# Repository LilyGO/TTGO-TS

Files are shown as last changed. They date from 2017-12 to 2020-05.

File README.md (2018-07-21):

## TTGO-TS

### TS V1.4

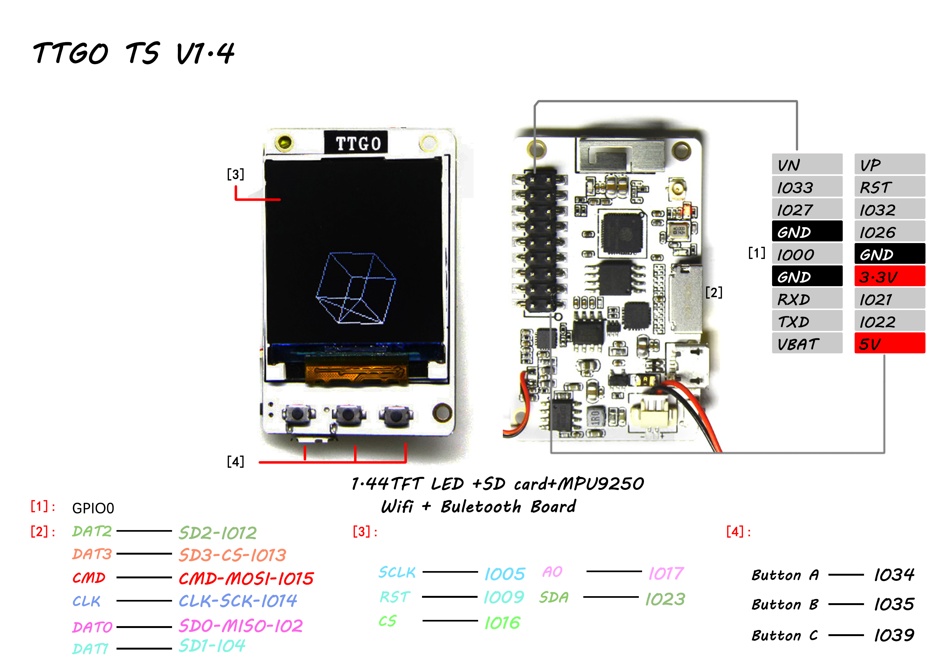
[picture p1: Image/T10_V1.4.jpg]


### TS V1.2

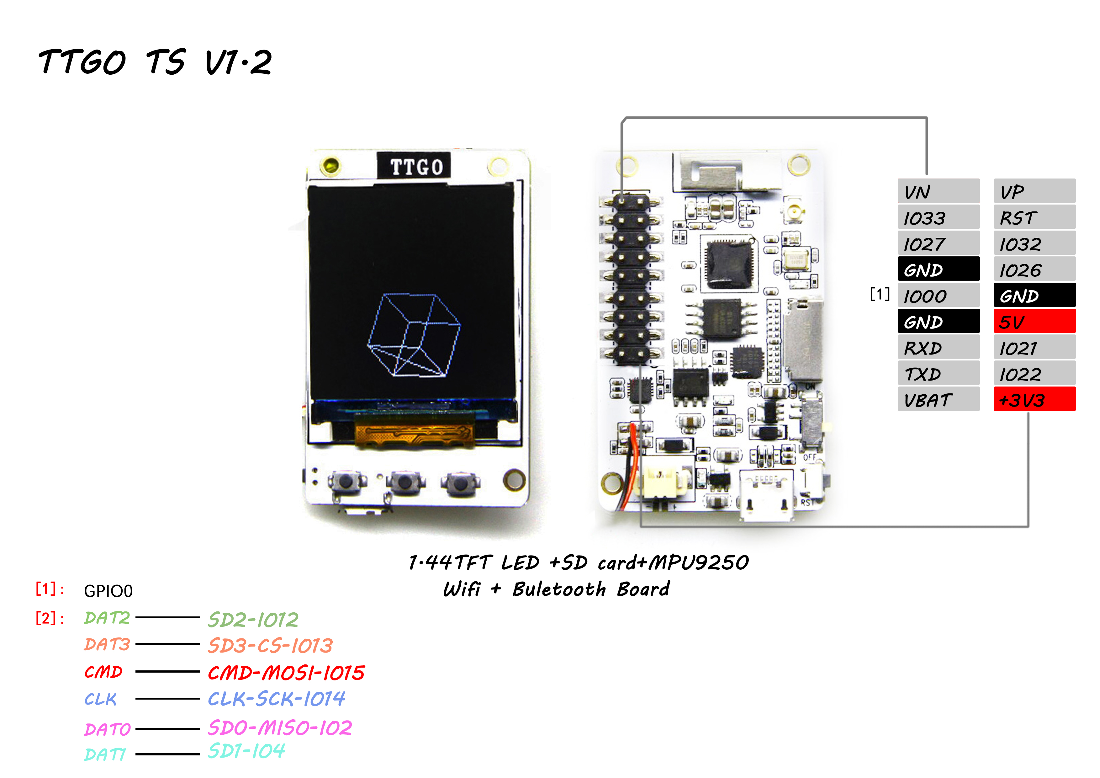
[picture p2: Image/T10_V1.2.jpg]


## TTGO-TS-V1.0

CS  16

DC  17

SDA 23

SCK 5

RST 9

## 3D shell

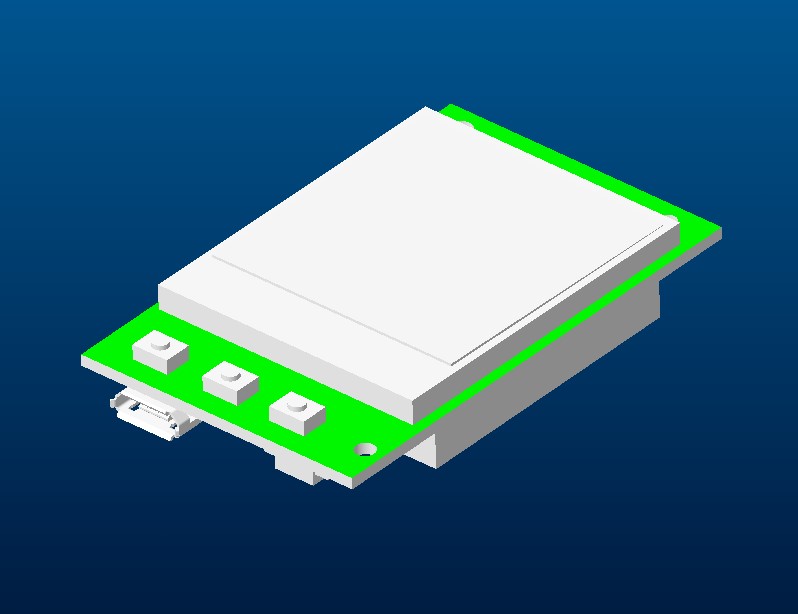
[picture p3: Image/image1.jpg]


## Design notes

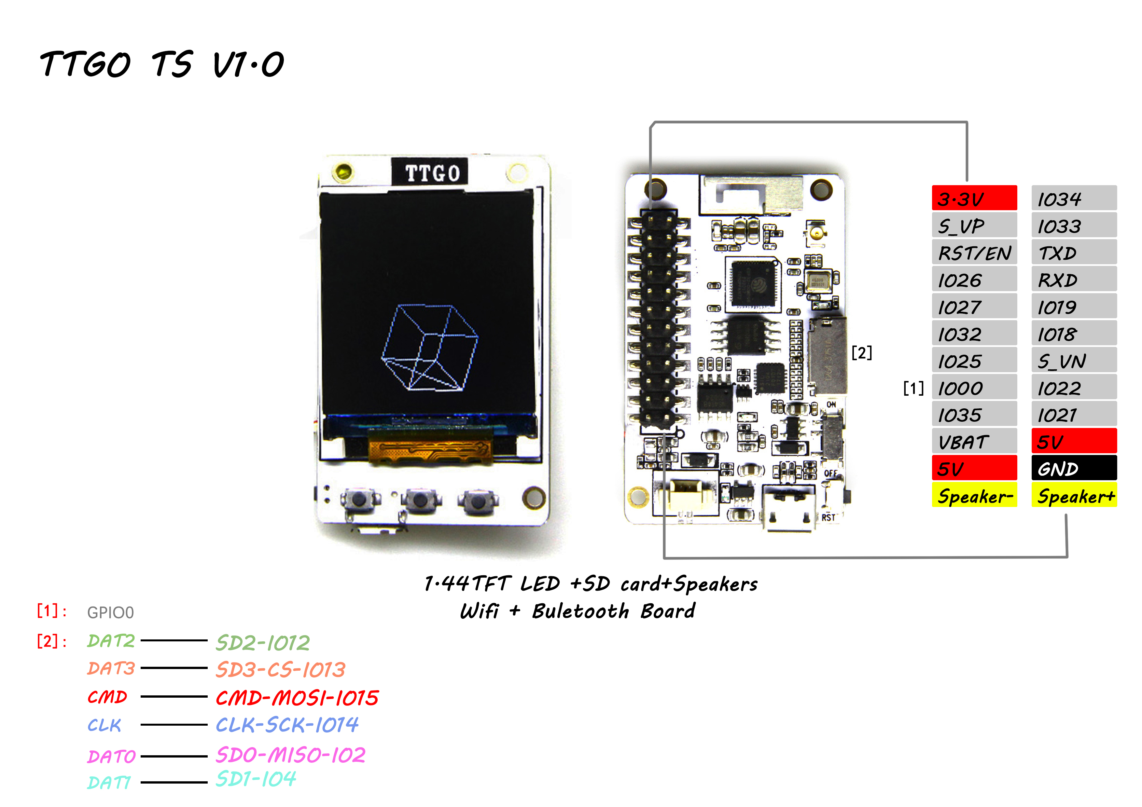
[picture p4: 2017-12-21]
Image/TS V1.0.jpg

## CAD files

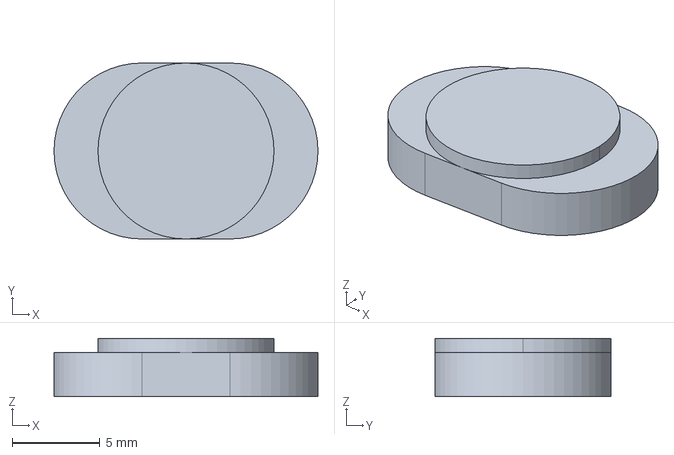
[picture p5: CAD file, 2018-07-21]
stp_file/laba.stp
15.0 x 10.0 x 3.30 mm

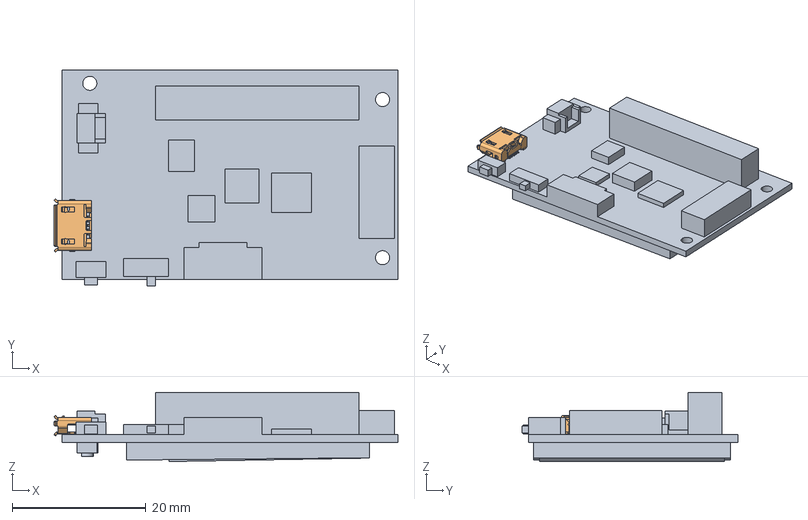
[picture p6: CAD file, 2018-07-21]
stp_file/pcb.stp
51.4 x 32.3 x 10.3 mm

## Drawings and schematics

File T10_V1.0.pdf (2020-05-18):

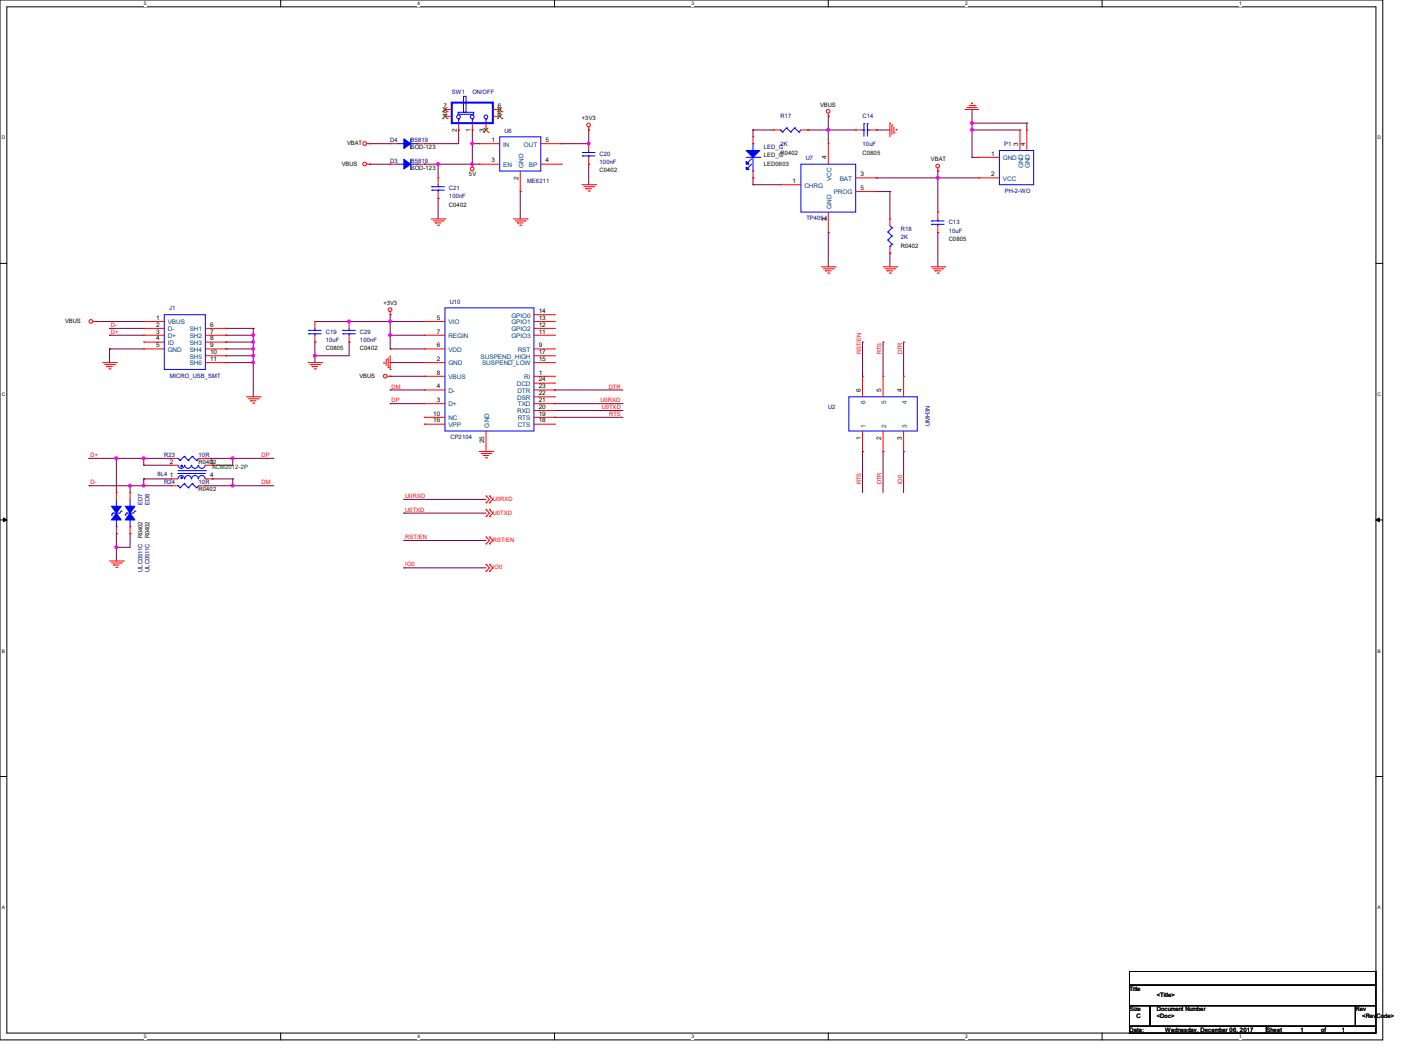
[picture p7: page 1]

2KR0402 U10 CP2104 VIO 5 REGIN 7 VDD 6 GND 2 VBUS 8 D- 4 D+

C C

# LED_4*15mA SCL/IO5 SDA/IO23 DC/IO17 CS/IO16 RST/EN

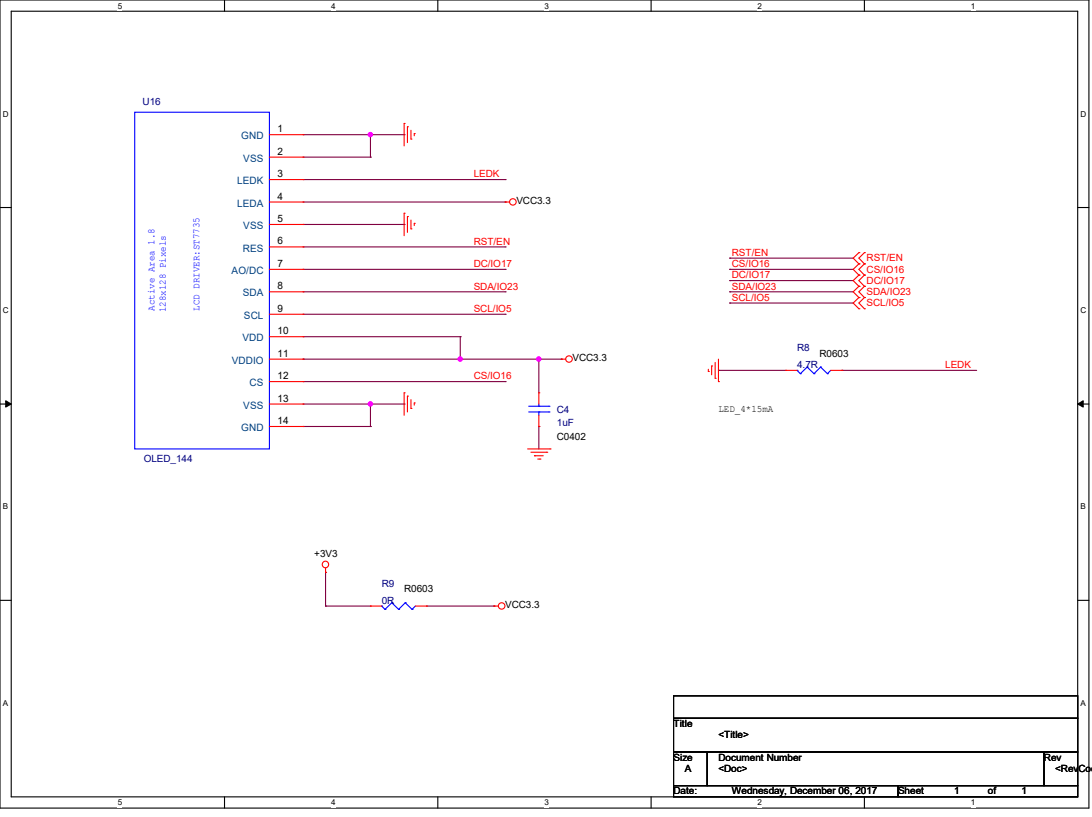
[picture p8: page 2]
LEDK; DC/IO17 SDA/IO23 SCL/IO5 CS/IO16 VCC3.3; VCC3.3 +3V3; VCC3.3; Title Size; Document Number; Rev Date:; Sheet; of <Doc>; <RevCode>; <Title> A; Wednesday, December 06, 2017; 1 Title Size; 1uF C0402 Active Area 1.8 128x128 Pixels; LCD DRIVER:ST7735 U16; OLED_144; GND; 1 VSS; LEDA; 4 VSS; 5 RES; 7 SDA; 8 SCL; 9 VDD; 10 VDDIO; 12 VSS; 13 GND

LEDK RST/EN

RST/EN
CS/IO16 DC/IO17 SDA/IO23 SCL/IO5

C C

+3V3

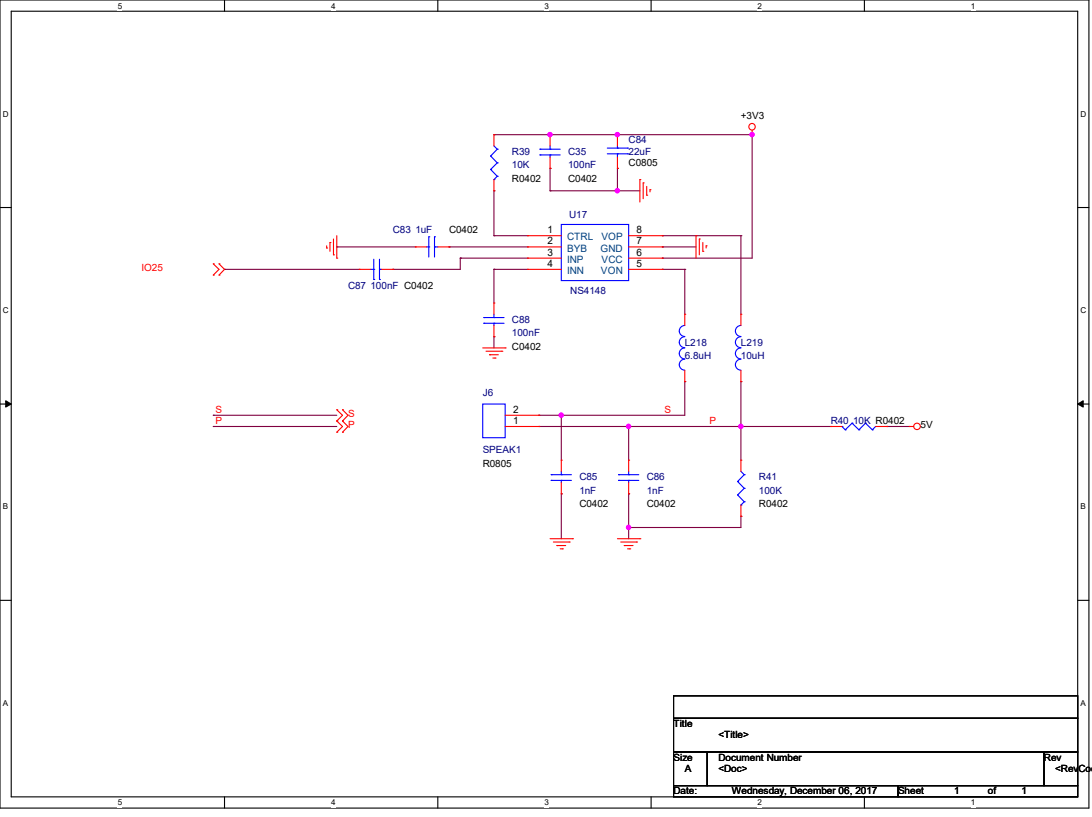
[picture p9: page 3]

# IO0 SD1-IO4 SD0-MISO-IO2SD2-IO12 CLK-SCK-IO14

# IO0 U0RXD

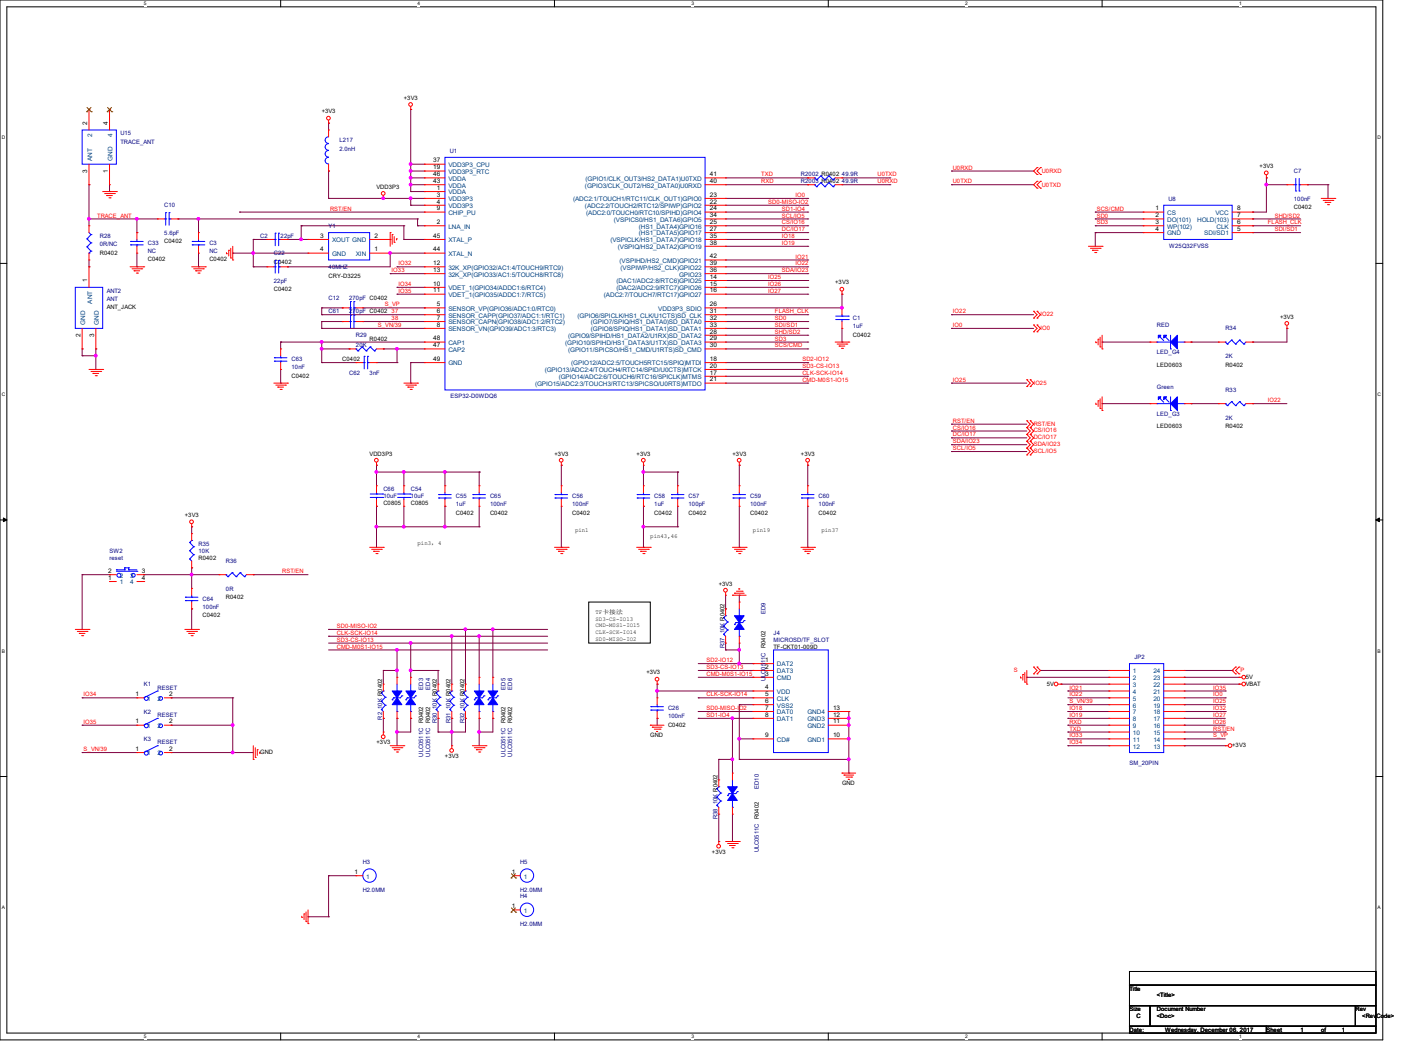
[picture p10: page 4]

SHD/SD2 TXD
IO18 DC/IO17 CS/IO16 SCL/IO5 RXD

SCL/IO5 SDA/IO23 DC/IO17 CS/IO16 RST/EN

CS/IO16 DC/IO17 SDA/IO23 SCL/IO5 RST/EN

1 R³⁷ ¹⁰K R⁰⁴⁰² ED⁶ ULC⁰⁵¹¹C R⁰⁴⁰² C54

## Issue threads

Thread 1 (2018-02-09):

MPU9250

donesnowangel, 2018-02-09:
Hi, I'm trying to work with the MPU9250 onboard the board with 1.8 inch screen. Can you please give me some guidance as to how to use it? What pins it is on? Is it on I2C or SPI? I've tried using various sketches examples and libraries, but without any success. An i2c scanner says there are no devices and when I try to get an a WHO_AM_I, I get a 0xFF.

Thanks,
Daniel

circuitsforfun, 2018-02-18:
Same problem here, I have both the 1.4" and 1.8" screen version and can't get the MPU9250 to work.
It would be great to see some example code provided or the schematic so I can see how it is connected.

donesnowangel, 2018-02-18:
I actually got it to work. Apparently the IMU uses pins 19 and 18 for SDA and SCL. So if you use the standard Wire.h library, add Wire.begin(19,18);

Daniel

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

circuitsforfun, 2018-02-18:
Ahh yes, that did the trick... thank you!

BeatArnet, 2018-05-19:
Hi, Could you please post an arduino example with the MPU9250. Thanks a lot.

LilyGO, 2018-12-19:
https://github.com/LilyGO/TTGO-TS-V1.2/blob/master/MPU9/MPU9.ino

kotakomputer, 2019-06-20:
TTGO V2.1_1.6 does not have PIN 18. Any recomended PIN?

Closed 2018-12-19.

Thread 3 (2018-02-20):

button example - strange behavior

GittaHuby, 2018-02-20:
The button example does not work properly: If i press btn A down it works as expected. While releasing btn A the serial monitor writes 'btn B released'. Physically buttons B and C without any function. Any idea?

kosso, 2018-03-12:
Through some trial and error I have discovered the v1.2 board (with gyro) has these pin numbers for the three pins (using the same orientation as the photo) :
~~~
LEFT 35
MIDDLE 34
RIGHT 39
~~~

Note: Some of the examples use M5Stack.h (from a very similar board. Is this a dev version?) which defines BUTTON_A_PIN 39, BUTTON_B_PIN 38 and BUTTON_C_PIN 37 which are wrong (at least for the V1.2 board containing the gyro and fewer physical pins).

This is why the example doesn't work.

jvhaarst, 2018-06-02:
This works for me :
```
#include <RBD_Timer.h>  // https://github.com/alextaujenis/RBD_Timer
#include <RBD_Button.h> // https://github.com/alextaujenis/RBD_Button

// input pullup enabled by default
RBD::Button left_button(35);
RBD::Button middle_button(34);
RBD::Button right_button(39);

void setup() {
  Serial.begin(115200);
}

void loop() {
  if(left_button.onPressed()) {
    Serial.println("Left Button Pressed");
  }

  if(left_button.onReleased()) {
    Serial.println("Left Button Released");
  }
  if(middle_button.onPressed()) {
    Serial.println("Middle Button Pressed");
  }

  if(middle_button.onReleased()) {
    Serial.println("Middle Button Released");
  }
  if(right_button.onPressed()) {
    Serial.println("Right Button Pressed");
  }

  if(right_button.onReleased()) {
    Serial.println("Right Button Released");
  }
}
```

GittaHuby, 2018-06-10:
Perfect ! Many Thanks, now it also works for me.
best regards

Closed 2018-06-10.

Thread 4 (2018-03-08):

mySD library?

Galbi3000, 2018-03-08:
I am using a v1.2 device. In the SD example you #include a header file called mySD.h but you do not include this library anywhere in the Git project.

According to your device diagram and looking at the ESP32__goodSD.ino source code I see that you have connected the SD card in a non-standard way for the ESP32. For example you use IO15 for MOSI but the standard SD library for ESP32 uses the designated MOSI pin of the ESP32 (IO23) so it would seem your custom mySD library is required to make the SD card work on your device!

Where can I find this library?

kosso, 2018-03-09:
Same issue.
The file `mySD.h` does not exist.

kosso, 2018-03-09:
I see the files required exist in this library: https://github.com/nhatuan84/esp32-micro-sdcard

But I still cannot get it to work.

Anyone have any idea what the correct pin settings are for the `SD.begin()` statement?

ririfonfon, 2018-03-11:
SD.begin(13,15,2,14) with V1.0 it work.

ririfonfon, 2018-03-11:
SD.begin(13,15,2,14)
13=SD3-CS
15=CMD-MOSI
2=SDO-MISO
14=CLK-SCK

kosso, 2018-03-12:
@ririfonfon Thanks!  That worked on my V1.2.

Now I need the pin numbers for the 3 buttons. Any idea?  Thanks.

kosso, 2018-03-12:
Update: It's OK. I've discovered through some trial and error that the 3 button pins are (in the orientation of the photo):
~~~
LEFT 35
MIDDLE 34
RIGHT 39
~~~

(Note: The examples use `M5Stack.h` (from a very similar board. Is this a dev version?) which defines `BUTTON_A_PIN 39`, `BUTTON_B_PIN 38` and `BUTTON_C_PIN 37`  which are wrong (at least for the V1.2 board containing the gyro and fewer physical pins)

ririfonfon, 2018-03-12:
yes i use RBD_Button  https://github.com/alextaujenis/RBD_Button
35 34 39
but if i use the m5stack.h the screen don't work
the screen in the lib. is ILI9341 and on the ttgo ts v1.0 is ST7735

do you have another lib. for the speaker ?
or the gpio ?

kosso, 2018-03-12:
For the screen, I found the Adafruit_ST7735 library worked :

```
#include <Adafruit_GFX.h>    // Core graphics library
#include <Adafruit_ST7735.h> // Hardware-specific library
#include <SPI.h>

#define TFT_CS   10
#define TFT_RST  9
#define TFT_DC   8
#define TFT_SCLK 13
#define TFT_MOSI 11

//Adafruit_ST7735 tft = Adafruit_ST7735(TFT_CS, TFT_DC, TFT_MOSI, TFT_SCLK, TFT_RST);
Adafruit_ST7735 tft = Adafruit_ST7735(16, 17, 23, 5, 9); // CS,A0,SDA,SCK,RESET

float p = 3.1415926;

void setup(void) {
  Serial.begin(115200);
  Serial.print("Hello! ST7735 TFT Test");

  // Use this initializer if you're using a 1.8" TFT
  tft.initR(INITR_BLACKTAB);   // initialize a ST7735S chip, black tab

  Serial.println("Initialized");

  //tft.setRotation(0); [0-3]

  tft.fillScreen(ST7735_BLACK);

  delay(500);

  // large block of text
  tft.fillScreen(ST7735_RED);
  tft.setTextColor(ST7735_WHITE);
  tft.setTextSize(1);
  tft.setCursor(2, 2);

  // Wrap some text, changing the colour of the words on the way.
  tft.setTextWrap(true);
  testdrawtext("hello world! ", ST7735_WHITE);
  testdrawtext("hello world! ", ST7735_BLACK);
  testdrawtext("hello world! ", ST7735_WHITE);
  testdrawtext("hello world! ", ST7735_BLACK);
  testdrawtext("hello world! ", ST7735_WHITE);
  testdrawtext("hello world! ", ST7735_BLACK);
  testdrawtext("hello world! ", ST7735_WHITE);
  testdrawtext("hello world! ", ST7735_BLACK);
  testdrawtext("hello world! ", ST7735_WHITE);
  testdrawtext("hello world! ", ST7735_BLACK);
  testdrawtext("hello world! ", ST7735_WHITE);
  testdrawtext("hello world! ", ST7735_BLACK);
  testdrawtext("hello world! ", ST7735_WHITE);
  testdrawtext("hello world! ", ST7735_BLACK);
  testdrawtext("hello world! ", ST7735_WHITE);
  testdrawtext("hello world! ", ST7735_BLACK);
  testdrawtext("hello world! ", ST7735_WHITE);
  testdrawtext("hello world! ", ST7735_BLACK);
  testdrawtext("hello world! ", ST7735_WHITE);
  testdrawtext("hello world! ", ST7735_BLACK);
  testdrawtext("hello world! ", ST7735_WHITE);
  testdrawtext("hello world! ", ST7735_BLACK);
  testdrawtext("hello world! ", ST7735_WHITE);
  testdrawtext("hello world! ", ST7735_BLACK);
  testdrawtext("hello world! ", ST7735_WHITE);
  testdrawtext("hello world! ", ST7735_BLACK);
  testdrawtext("hello world! ", ST7735_WHITE);
  testdrawtext("hello world! ", ST7735_BLACK);
  testdrawtext("hello world! ", ST7735_WHITE);
  testdrawtext("hello world! ", ST7735_BLACK);
  testdrawtext("hello world! ", ST7735_WHITE);
  testdrawtext("hello world! ", ST7735_BLACK);

  delay(1000);

  // tft print function!
  tftPrintTest();
  delay(4000);

  // a single pixel
  tft.drawPixel(tft.width()/2, tft.height()/2, ST7735_GREEN);
  delay(500);

  // line draw test
  testlines(ST7735_YELLOW);
  delay(500);

  // optimized lines
  testfastlines(ST7735_RED, ST7735_BLUE);
  delay(500);

  testdrawrects(ST7735_GREEN);
  delay(500);

  testfillrects(ST7735_YELLOW, ST7735_MAGENTA);
  delay(500);
  tft.fillScreen(ST7735_BLACK);
  testfillcircles(10, ST7735_BLUE);
  testdrawcircles(10, ST7735_WHITE);
  delay(500);

  testtriangles();
  delay(500);

  mediabuttons();
  delay(500);

  Serial.println("done");
  delay(1000);
}

void loop() {
  tft.invertDisplay(true);
  delay(500);
  tft.invertDisplay(false);
  delay(500);
}

void testlines(uint16_t color) {
  tft.fillScreen(ST7735_BLACK);
  for (int16_t x=0; x < tft.width(); x+=6) {
    tft.drawLine(0, 0, x, tft.height()-1, color);
  }
  for (int16_t y=0; y < tft.height(); y+=6) {
    tft.drawLine(0, 0, tft.width()-1, y, color);
  }

  tft.fillScreen(ST7735_BLACK);
  for (int16_t x=0; x < tft.width(); x+=6) {
    tft.drawLine(tft.width()-1, 0, x, tft.height()-1, color);
  }
  for (int16_t y=0; y < tft.height(); y+=6) {
    tft.drawLine(tft.width()-1, 0, 0, y, color);
  }

  tft.fillScreen(ST7735_BLACK);
  for (int16_t x=0; x < tft.width(); x+=6) {
    tft.drawLine(0, tft.height()-1, x, 0, color);
  }
  for (int16_t y=0; y < tft.height(); y+=6) {
    tft.drawLine(0, tft.height()-1, tft.width()-1, y, color);
  }

  tft.fillScreen(ST7735_BLACK);
  for (int16_t x=0; x < tft.width(); x+=6) {
    tft.drawLine(tft.width()-1, tft.height()-1, x, 0, color);
  }
  for (int16_t y=0; y < tft.height(); y+=6) {
    tft.drawLine(tft.width()-1, tft.height()-1, 0, y, color);
  }
}

void testdrawtext(char *text, uint16_t color) {
  tft.setTextColor(color);

  tft.print(text);
}

void testfastlines(uint16_t color1, uint16_t color2) {
  tft.fillScreen(ST7735_BLACK);
  for (int16_t y=0; y < tft.height(); y+=5) {
    tft.drawFastHLine(0, y, tft.width(), color1);
  }
  for (int16_t x=0; x < tft.width(); x+=5) {
    tft.drawFastVLine(x, 0, tft.height(), color2);
  }
}

void testdrawrects(uint16_t color) {
  tft.fillScreen(ST7735_BLACK);
  for (int16_t x=0; x < tft.width(); x+=6) {
    tft.drawRect(tft.width()/2 -x/2, tft.height()/2 -x/2 , x, x, color);
  }
}

void testfillrects(uint16_t color1, uint16_t color2) {
  tft.fillScreen(ST7735_BLACK);
  for (int16_t x=tft.width()-1; x > 6; x-=6) {
    tft.fillRect(tft.width()/2 -x/2, tft.height()/2 -x/2 , x, x, color1);
    tft.drawRect(tft.width()/2 -x/2, tft.height()/2 -x/2 , x, x, color2);
  }
}

void testfillcircles(uint8_t radius, uint16_t color) {
  for (int16_t x=radius; x < tft.width(); x+=radius*2) {
    for (int16_t y=radius; y < tft.height(); y+=radius*2) {
      tft.fillCircle(x, y, radius, color);
    }
  }
}
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
BorisFR, 2018-05-07:
I have found the same info for screen, except I  put RST to -1.
Do you not if it is possible to put the screen backlight off?

jvhaarst, 2018-06-02:
For me the default library works, using this code :
```
#include "SD.h"
#include "SPI.h"

#define PIN_NUM_MISO 2
#define PIN_NUM_MOSI 15
#define PIN_NUM_CLK  14
#define PIN_NUM_CS   13

void setup() {
    Serial.begin(115200);
    SPI.begin(PIN_NUM_CLK, PIN_NUM_MISO, PIN_NUM_MOSI, PIN_NUM_CS);
    if(!SD.begin(PIN_NUM_CS)){
        Serial.println("Card Mount Failed");
        return;
    }
    uint64_t cardSize = SD.cardSize() / (1024 * 1024);
    Serial.printf("SD Card Size: %lluMB\n", cardSize);
}
void loop() {}
```

ydsdsy, 2018-08-02:
Hi,
Update :
I found this code and with a little tweaking it came to work for me :
[https://github.com/LilyGO/TTGO-TS-V1.2/blob/master/TEST_SD/ESP32__goodSD.ino](url)
i can correctly see the sdcard and the files on it, can write and read the files....
it all came down to this settings : SD.begin(23,5,19,18)

complete working code below :
` // include the SD library:
#include <SPI.h>
#include <mySD.h>

File root;

void setup()
{
  Serial.begin(115200);
  Serial.print("Initializing SD card...");
  /* initialize SD library with SPI pins */
 if (!SD.begin(23,5,19,18)) {            //T1:13,15,2,14  T2: 23,5,19,18
    Serial.println("initialization failed!");
    return;
  }
  Serial.println("initialization done.");
  /* Begin at the root "/" */
  root = SD.open("/");
  if (root) {
    printDirectory(root, 0);
    root.close();
  } else {
    Serial.println("error opening test.txt");
  }
  /* open "test.txt" for writing */
  root = SD.open("test.txt", FILE_WRITE);
  /* if open succesfully -> root != NULL
    then write string "Hello world!" to it
  */
  if (root) {
    root.println(" Dog : Luna : 0,128s : 4,058s : 4,186s : ");
    root.flush();
   /* close the file */
    root.close();
  } else {
    /* if the file open error, print an error */
    Serial.println("error opening test.txt");
  }
  delay(1000);
  /* after writing then reopen the file and read it */
  root = SD.open("test.txt");
  if (root) {
    /* read from the file until there's nothing else in it */
    while (root.available()) {
      /* read the file and print to Terminal */
      Serial.write(root.read());
    }
    root.close();
  } else {
    Serial.println("error opening test.txt");
  }

  Serial.println("done!");
}

void loop()
{}

void printDirectory(File dir, int numTabs) {

  while(true) {
     File entry =  dir.openNextFile();
     if (! entry) {
       break;
     }
     for (uint8_t i=0; i<numTabs; i++) {
       Serial.print('\t');   // we'll have a nice indentation
     }
     // Print the name
     Serial.print(entry.name());
     /* Recurse for directories, otherwise print the file size */
     if (entry.isDirectory()) {
       Serial.println("/");
       printDirectory(entry, numTabs+1);
     } else {
       /* files have sizes, directories do not */
       Serial.print("\t\t");
       Serial.println(entry.size());
     }
     entry.close();
   }
}`

Yves,

LilyGO, 2018-12-19:
https://github.com/nhatuan84/esp32-micro-sdcard

bnmahajan78, 2019-01-06:
This approach  worked form me .

#include "FS.h"
#include "SD.h"
#include "SPI.h"

#define PIN_NUM_MISO 2
#define PIN_NUM_MOSI 15
#define PIN_NUM_CLK  14
#define PIN_NUM_CS   13

void setup(){
    Serial.begin(115200);

   // if(!SD.begin()){
   //     Serial.println("Card Mount Failed");
   //     return;
   // }

    SPI.begin(PIN_NUM_CLK, PIN_NUM_MISO, PIN_NUM_MOSI, PIN_NUM_CS);
    if(!SD.begin(PIN_NUM_CS)){
        Serial.println("Card Mount Failed");
        return;
    }

    uint64_t cardSize = SD.cardSize() / (1024 * 1024);
    Serial.printf("SD Card Size: %lluMB\n", cardSize);
    uint8_t cardType = SD.cardType();

    if(cardType == CARD_NONE){
        Serial.println("No SD card attached");
        return;
    }

    Serial.print("SD Card Type: ");
    if(cardType == CARD_MMC){
        Serial.println("MMC");
    } else if(cardType == CARD_SD){
        Serial.println("SDSC");
    } else if(cardType == CARD_SDHC){
        Serial.println("SDHC");
    } else {
        Serial.println("UNKNOWN");
    }

    uint64_t cardSize = SD.cardSize() / (1024 * 1024);
    Serial.printf("SD Card Size: %lluMB\n", cardSize);

    Serial.printf("Total space: %lluMB\n", SD.totalBytes() / (1024 * 1024));
    Serial.printf("Used space: %lluMB\n", SD.usedBytes() / (1024 * 1024));
}

void loop(){

}

Closed 2018-12-19.

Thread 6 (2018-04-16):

Screen alignment

BorisFR, 2018-04-16:
I'm using the adafruit lib like this:
`#include <Adafruit_GFX.h>    // Core graphics library
#include <Adafruit_ST7735.h> // Hardware-specific library
#include <SPI.h>
#define TFT_RST     -1
#define TFT_SCLK    5
#define TFT_CS      16
#define TFT_DC      17
#define TFT_MOSI    23
Adafruit_ST7735 tft = Adafruit_ST7735(TFT_CS, TFT_DC, TFT_MOSI, TFT_SCLK, TFT_RST);

void box (uint8_t x, uint8_t y, uint8_t width, uint8_t height, uint16_t color) {
    for(uint8_t i=x; i<(x+width); i++)
        for(uint8_t j=y;j<(y+height);j++)
            tft.drawPixel(i, j, color);
}

void setup() {
tft.initR(INITR_BLACKTAB);
tft.fillScreen(ST7735_BLACK);
box(0,0,17,17,ST7735_CYAN);
box(1,1,15,15,ST7735_RED);
box(2,2,13,13,ST7735_WHITE);
box(3,3,11,11,ST7735_BLUE);
}
`
Display on the left start with white (missing cyan and red), and on top with red (missing cyan). And there is also garbage on the screen at right and bottom as fillscreen ... don't fill the screen.

Do you have the same problem?

jvhaarst, 2018-06-02:
This is about 10 times faster than the example the board came with :
```
#include <TFT_eSPI.h> // Hardware-specific library
#include <SPI.h>

TFT_eSPI tft = TFT_eSPI();       // Invoke custom library

float r, x1, ya, z1, x2, y2, z2, x3, y3, z3;               //
int f[8][2], x, y;                                         // Draw box, x, y center
int c[8][3] = {                                            // Cube
 {-20,-20, 20},{20,-20, 20},{20,20, 20},{-20,20, 20},
 {-20,-20,-20},{20,-20,-20},{20,20,-20},{-20,20,-20} };
//uint32_t fstart = 0;  // start time for frame rate calculation
//uint32_t fend = 0;    // end time for frame rate calculation
//float fps = 0;        // Used in frame rate calculation

void setup(void) {
  //Serial.begin(115200);
  tft.init();
  tft.fillScreen(TFT_BLACK);                                // CLEAR
  tft.setTextColor(TFT_GREEN);                     
  tft.setRotation(1);                                      //
  x = tft.width() /2; x = x + 14;                          // x Center Calculate
  y = tft.height()/2;                                      // y Center Calculate
}

void loop(){
 for (int a = 0; a <= 360; a = a + 2 ) {                   // 0 to 360 degree
   for (int i = 0; i < 8; i++) {                           //
    r  = a * 0.0174532;                                    // 1 degree
    x1 = c[i][2] * sin(r) + c[i][0] * cos(r);              // rotate Y
    ya = c[i][1];                                          //
    z1 = c[i][2] * cos(r) - c[i][0] * sin(r);              //
    x2 = x1;                                               //
    y2 = ya * cos(r) - z1 * sin(r);                        // rotate X
    z2 = ya * sin(r) + z1 * cos(r);                        //
    x3 = x2 * cos(r) - y2 * sin(r);                        // rotate Z
    y3 = x2 * sin(r) + y2 * cos(r);                        //
    z3 = z2; x3 = x3 + x ; y3 = y3 + y ;                   //
    f[i][0] = x3; f[i][1] = y3; f[i][2] = z3;              // store new values
   }
   //fstart = millis();
   tft.fillScreen(TFT_BLACK);
   tft.drawLine(f[0][0],f[0][1],f[1][0],f[1][1],TFT_WHITE);
   tft.drawLine(f[1][0],f[1][1],f[2][0],f[2][1],TFT_WHITE);
   tft.drawLine(f[2][0],f[2][1],f[3][0],f[3][1],TFT_WHITE);
   tft.drawLine(f[3][0],f[3][1],f[0][0],f[0][1],TFT_WHITE);
   tft.drawLine(f[4][0],f[4][1],f[5][0],f[5][1],TFT_WHITE);
   tft.drawLine(f[5][0],f[5][1],f[6][0],f[6][1],TFT_WHITE);
   tft.drawLine(f[6][0],f[6][1],f[7][0],f[7][1],TFT_WHITE);
   tft.drawLine(f[7][0],f[7][1],f[4][0],f[4][1],TFT_WHITE);
   tft.drawLine(f[0][0],f[0][1],f[4][0],f[4][1],TFT_WHITE);
   tft.drawLine(f[1][0],f[1][1],f[5][0],f[5][1],TFT_WHITE);
   tft.drawLine(f[2][0],f[2][1],f[6][0],f[6][1],TFT_WHITE);
   tft.drawLine(f[3][0],f[3][1],f[7][0],f[7][1],TFT_WHITE);
   tft.drawLine(f[1][0],f[1][1],f[3][0],f[3][1],TFT_WHITE);// cross
   tft.drawLine(f[0][0],f[0][1],f[2][0],f[2][1],TFT_WHITE);// cross
   //fend = millis();
   //fps = (1000) / (fend-fstart);
   //tft.drawFloat(fps, 0, 0, 2);
   //Serial.print(fps); Serial.println("fps");// Show frame rate
   //delay(5);
 }
}
```
(on my board, the fps is about 60)

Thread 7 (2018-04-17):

which board do I use?

davidm-public, 2018-04-17:
Hi, I have version 1.2.

Wondering which board I select in the Arduino IDE?

Thanks

BorisFR, 2018-04-18:
Personally, I use "ESP32 dev module"

LilyGO, 2018-05-05:
Sorry, I forgot to replace my new e-mail. @BorisFR He is good.

Closed 2018-12-19.

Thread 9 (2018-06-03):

Does this board have a speaker connection?

joedeveloper, 2018-06-03:
I'd like a board with screen, MPU, SD Card reader, battery connector + charging circuit, and reasonably easy to attach to a speaker - which one would that be?

LilyGO, 2018-12-19:
Yes, it has these features

Closed 2018-12-19.

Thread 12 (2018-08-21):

Usb Problem,

yunusde, 2018-08-21:
I bought the 1.44 version and when i plug usb to computer, it does power up but there is nothing with com port or what so ever. i can't see in the device manager too.

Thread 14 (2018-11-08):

Pin header type

markdesouza, 2018-11-08:
The pins on the board seem to be shorter than standard dupont pins. As such dupont connectors tend to slide of easily. What is the correct header type for these pins.

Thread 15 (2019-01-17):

TS v1.0 Battery powered

albkirk, 2019-01-17:
Hello,
  I'm feeding the TS v1.0 with a 18650 connected using the supplied little power cable. The battery can be charged using the Micro USB port with no problem. The Comunication with PC is pretty good and the SW loaded on ESP32 runs fine when powered via USB.
   My issue is that when power is supplied by the battery the unit hangs/reboot/crash with the battery level lower than 3.9v! Even with fresh charged battery, the screen light dims on every task, such play a beep on the speaker, read a value from ADC, reading from SD card,etc.
  Does anyone also experience this issue?
  Is there anything I could do to fix its power stability?

BR,
Nuno

sfambach, 2020-05-21:
Hi, which version do you have? I have Version 1.2 with 1.4" display and MPU.  I am running the board with a 3.7V 1500mAh Lipo and it workes find for me, no crashes on beep, display changes or on  any other current consuming action. I have currently not checked with SD card but will do today.
BR SFA

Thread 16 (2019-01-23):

TTGO ts v1.4 sleep tft

WaterC88, 2019-01-23:
i already try tft example the 3d animation cube , its workn o problem,
now i need to try turn off the screen,how to sleep the tft(turn off for power efficiency)?
i look many place still don get answer..
is the tft power come from the vcc or i can just turn of some pin?
please help, thank before...sorry for my english

Vinschni, 2019-06-14:
I have the same issue.
Sending the commands 0x10 or 0x11 does not power off the 1.44 inch tft.

Vinschni, 2019-06-14:
I ask the question in other words:

**How to power off the backlight of the tft display?**

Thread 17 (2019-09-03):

Proper button pinout???

jhoughjr, 2019-09-03:
accoreding to the docs, left is 34, middle is 35 and right is 39.
However with these settings, 34 is the middle button and no other buttons work.

roboter, 2020-01-15:
What board do you have?

For v1.0 I have

#define BUTTON_1    35
#define BUTTON_2    34
#define BUTTON_3    39

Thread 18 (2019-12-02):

V1.2 Backlight on/off

aaronh86, 2019-12-02:
Is there any way to turn off the backlight - pin 27 doesn't seem to work?

Closed 2019-12-02.

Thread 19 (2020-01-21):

Battery voltage

dastrobbel, 2020-01-21:
I want to read the battery lvl of a lipo 3.7V battery and need to no what pin it uses. I already read the pins from 0 to 40. But none gave the right value.

sfambach, 2020-05-21:
Hi, I tried to find out if there is a pin already assigned over a resitance bridge or something else but i found no circuit diagram. Would it at least be possible to post a full ciruit diagram instead of the shrinked one that is on git. Or is it possible to do something over the vbus?
Thank in advanced for you reply SFA

G6EJD, 2020-12-09:
There is no on-board voltage divider. You have to wire one externally from Vbat to A0 (goio17)

Konjohn, 2022-10-05:
Hi, Can someone solve this problem?

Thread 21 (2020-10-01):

Backlight not working when I upload sample code

joshuaokpako, 2020-10-01:
I am using the 1.8" and 1.44" TFT screen and when I upload the sample code, the backlight goes off completely but the program works fine and shows the correct display on the screen but the back light doesn't work

sfambach, 2020-10-01:
Can you post your code, this could help. Check the pin for backlight this pin 27. Set it to output and to high value.

joshuaokpako, 2020-10-02:
Yes thank you that was the issue. It worked.  I did not know that pin 27 was for the backlight

Closed 2020-10-02.

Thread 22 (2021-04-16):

TTGO TS I²C communication address

yusufCHE, 2021-04-16:
Hi
how can I find the adresse of TTGO TS used in I²C communication?

sfambach, 2021-04-17:
Hi, i dont know if I get the question. Which I2C address do you mean, if you use it as a client you can set the address. If you need an address of peripherie there are some scanner for wire bus on the net or use the examples.
If this does not help, please clarify you needs.

yusufCHE, 2021-04-17:
I want to use it as a slave and the arduino as master.
I used the code scanner with arduino but it doesn't work. I didn't use pullup resistors so I suppose that its is integrated in the TTGO TS.
Thank you

sfambach, 2021-04-17:
Then you need to create a programm  for the TS and let it work as a I2C client. You can choose an adress for it. The basis of the TS, is  an ESP32 and its programmable with the arduino gui. Or you put an AT Firmware on the  ts and configure it with at commands. Be carful dependant on which arduino you use, you need an logic level converter from 5V to 3.3V.

yusufCHE, 2021-04-17:
So I don't have to use wire library to programme the TS, because in this library to assign the address to the Arduino UNO, for example, we have to write it as an argument of the function wire. Begin () which is different from the ESP32 board that uses (SCL, SDA) pins as arguments.
How can I assign an address to the ESP32 board ?
THANK YOU

sfambach, 2021-04-17:
Hi, sorry I was not aware that arduino does not support client mode for ESP32. I Thought this works as on arduino. Maybe you can follow this link: https://github.com/gutierrezps/ESP32_I2C_Slave.
BR

yusufCHE, 2021-04-17:
Thank you

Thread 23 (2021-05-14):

Screen won't turn on!

MaxSMoke777, 2021-05-14:
The unit I got from Amazon worked fine with it's pre-installed examples. but I haven't been able to get the screen to turn no matter what sketch or settings I use. The one exception is when I tried an M5 example, which causes the screen solid white. Otherwise it doesn't seem to respond to anything.

Is it possible I accidentally pushed some series of buttons that turns off the screen at a firmware level? If the screen was broken, it shouldn't be able to show white, right?

sfambach, 2021-05-14:
Hi, it is some time ago when i tested this device, I cant remember if there were specific problems. Ther are at least two different versions, but the settings (pins) for the displays looks the same.  Here is my test project you can have a look at the pin settings : https://github.com/sfambach/esp32/tree/master/project/TtgoTsJPegViewer. Here are some additional tests I made https://github.com/sfambach/esp32/tree/master/boards/TTGO_TS_V1.2_MPU9250.  If you post your code i can check it with my device if you want. BR Stef

MaxSMoke777, 2021-05-14:
Thanks for responding! I found out what the issue was and posted the fix in the Amazon review for anyone else unlucky enough to buy this janky board. The issue is that it's back-light has to be turned on by switching pin 27 to HIGH. Failure to do so means the screen appears broken. The board actually has a TFT_eSPI profile which does not, itself, have the setting to turn on the back-light.

It also didn't help that the board's name and appearance is alot like the TTGO TS, when it's really the T10-V2.0 board. They look identical in photos, but actually have separate libraries. It was when I found the right library, loaded an example that actually worked (many in the package actually don't), I noticed the back-light switch in setup and started adding it in. Adding that to the other examples fixed everything.

andrademarcos27, 2021-05-30:
@MaxSMoke777 , you said you found the right library. I am facing the same problem that you described earlier. Could you please share where you found a library that works?

MaxSMoke777, 2021-05-30:
> @MaxSMoke777 , you said you found the right library. I am facing the same problem that you described earlier. Could you please share where you found a library that works?

https://github.com/Xinyuan-LilyGO/LilyGo_Txx
(and don't forget to set 27 HIGH, or the back-light won't come on and it'll still look dead)

andrademarcos27, 2021-05-30:
Thanks @MaxSMoke777. Now it´s alive and working. Finally !!!

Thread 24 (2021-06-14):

MPU9250

capedra, 2021-06-14:
I can't get it to work on V1.2. I tested using two libraries: the m5stack one and the library you use on your example. None of them can read the values. I also need the INT pin of the module connected to some GPIO so I can use the Wake On Motion feature of the MPU9250, but I can see on the datasheet that this pin is NC (not connected). I wonder why it's disconnected since some people need to let the ESP32 deep sleeping and just let it wake up when the IMU detects some motion.

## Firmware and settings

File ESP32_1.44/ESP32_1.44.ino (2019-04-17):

 // ESP32 + 1.44" TFT v2.1                                  // 2017.02.08 macsbug
// http://www.sipatechmeetup.com/media/uploads/arduinoesp32dev.pdf
#include <Adafruit_GFX.h>                                  // Core graphics library
#include <Adafruit_ST7735.h>                               // Hardware-specific library
#include <mySD.h>
#define LED_BUILTIN 22
Adafruit_ST7735 tft = Adafruit_ST7735(16, 17, 23, 5, 9); // CS,A0,SDA,SCK,RESET
float r, x1, ya, z1, x2, y2, z2, x3, y3, z3;               //
int f[8][2], x, y;                                         // Draw box, x, y center
int c[8][3] = {                                            // Cube
 {-20,-20, 20},{20,-20, 20},{20,20, 20},{-20,20, 20},
 {-20,-20,-20},{20,-20,-20},{20,20,-20},{-20,20,-20} };
 File root;
 
void setup(void) {
  pinMode(27,INPUT);//Backlight:27
  digitalWrite(27,HIGH);//New version added to backlight control
  tft.initR(INITR_18GREENTAB);                             // 1.44 v2.1
  tft.fillScreen(ST7735_BLACK);                            // CLEAR
  tft.setTextColor(0x5FCC);                                // GREEN
  tft.setRotation(1);                                      // 
  x = tft.width() /2; x = x + 14;                          // x Center Calculat
  y = tft.height()/2;                                      // y Center Calculate
  Serial.begin(115200);
  pinMode(LED_BUILTIN, OUTPUT);
  Serial.print("Initializing SD card...");
  /* initialize SD library with SPI pins */
 if (!SD.begin(13, 15, 2, 14)) {            //T1:13,15,2,14  T2: 23,5,19,18
    Serial.println("initialization failed!");
    return;
  }
  Serial.println("initialization done.");
  /* Begin at the root "/" */
  root = SD.open("/");
  if (root) {    
    printDirectory(root, 0);
    root.close();
  } else {
    Serial.println("error opening test.txt");
  }
  /* open "test.txt" for writing */
  root = SD.open("test.txt", FILE_WRITE);
  /* if open succesfully -> root != NULL 
    then write string "Hello world!" to it
  */
  if (root) {
    root.println("Hello world!");
    root.flush();
   /* close the file */
    root.close();
  } else {
    /* if the file open error, print an error */
    Serial.println("error opening test.txt");
  }
  delay(1000);
  /* after writing then reopen the file and read it */
  root = SD.open("test.txt");
  if (root) {    
    /* read from the file until there's nothing else in it */
    while (root.available()) {
      /* read the file and print to Terminal */
      Serial.write(root.read());
    }
    root.close();
  } else {
    Serial.println("error opening test.txt");
  }
  
  Serial.println("done!");
  
}
 
void loop(){
 for (int a = 0; a <= 360; a = a + 2 ) {                   // 0 to 360 degree
   for (int i = 0; i < 8; i++) {                           //
    r  = a * 0.0174532;                                    // 1 degree
    x1 = c[i][2] * sin(r) + c[i][0] * cos(r);              // rotate Y
    ya = c[i][1];                                          //
    z1 = c[i][2] * cos(r) - c[i][0] * sin(r);              //
    x2 = x1;                                               //
    y2 = ya * cos(r) - z1 * sin(r);                        // rotate X
    z2 = ya * sin(r) + z1 * cos(r);                        //
    x3 = x2 * cos(r) - y2 * sin(r);                        // rotate Z
    y3 = x2 * sin(r) + y2 * cos(r);                        //
    z3 = z2; x3 = x3 + x ; y3 = y3 + y ;                   //
    f[i][0] = x3; f[i][1] = y3; f[i][2] = z3;              // store new values
   }
   tft.fillScreen(ST7735_BLACK);
   tft.drawLine(f[0][0],f[0][1],f[1][0],f[1][1],ST7735_WHITE);
   tft.drawLine(f[1][0],f[1][1],f[2][0],f[2][1],ST7735_WHITE);
   tft.drawLine(f[2][0],f[2][1],f[3][0],f[3][1],ST7735_WHITE);
   tft.drawLine(f[3][0],f[3][1],f[0][0],f[0][1],ST7735_WHITE);
   tft.drawLine(f[4][0],f[4][1],f[5][0],f[5][1],ST7735_WHITE);
   tft.drawLine(f[5][0],f[5][1],f[6][0],f[6][1],ST7735_WHITE);
   tft.drawLine(f[6][0],f[6][1],f[7][0],f[7][1],ST7735_WHITE);
   tft.drawLine(f[7][0],f[7][1],f[4][0],f[4][1],ST7735_WHITE);
   tft.drawLine(f[0][0],f[0][1],f[4][0],f[4][1],ST7735_WHITE);
   tft.drawLine(f[1][0],f[1][1],f[5][0],f[5][1],ST7735_WHITE);
   tft.drawLine(f[2][0],f[2][1],f[6][0],f[6][1],ST7735_WHITE);
   tft.drawLine(f[3][0],f[3][1],f[7][0],f[7][1],ST7735_WHITE);
   tft.drawLine(f[1][0],f[1][1],f[3][0],f[3][1],ST7735_WHITE);// cross
   tft.drawLine(f[0][0],f[0][1],f[2][0],f[2][1],ST7735_WHITE);// cross
 }
  digitalWrite(LED_BUILTIN, HIGH);   // turn the LED on (HIGH is the voltage level)
  delay(1000);                       // wait for a second
  digitalWrite(LED_BUILTIN, LOW);    // turn the LED off by making the voltage LOW
  delay(1000);                       // wait for a second
}

void printDirectory(File dir, int numTabs) {
  
  while(true) {
     File entry =  dir.openNextFile();
     if (! entry) {
       break;
     }
     for (uint8_t i=0; i<numTabs; i++) {
       Serial.print('\t');   // we'll have a nice indentation
     }
     // Print the name
     Serial.print(entry.name());
     /* Recurse for directories, otherwise print the file size */
     if (entry.isDirectory()) {
       Serial.println("/");
       printDirectory(entry, numTabs+1);
     } else {
       /* files have sizes, directories do not */
       Serial.print("\t\t");
       Serial.println(entry.size());
     }
     entry.close();
   }
}

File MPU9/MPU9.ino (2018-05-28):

#include <MPU9250_asukiaaa.h>
 
#ifdef _ESP32_HAL_I2C_H_
#define SDA_PIN 19
#define SCL_PIN 18
#endif
 
MPU9250 mySensor;
 
void setup() {
while(!Serial);
 
Serial.begin(115200);
Serial.println("started");
 
#ifdef _ESP32_HAL_I2C_H_
// for esp32
Wire.begin(19, 18); //sda, scl
#else
Wire.begin();
#endif
 
mySensor.setWire(&Wire);
 
mySensor.beginAccel();
mySensor.beginMag();
 
// you can set your own offset for mag values
// mySensor.magXOffset = -50;
// mySensor.magYOffset = -55;
// mySensor.magZOffset = -10;
}
 
void loop() {
mySensor.accelUpdate();
Serial.println("print accel values");
Serial.println("accelX: " + String(mySensor.accelX()));
Serial.println("accelY: " + String(mySensor.accelY()));
Serial.println("accelZ: " + String(mySensor.accelZ()));
Serial.println("accelSqrt: " + String(mySensor.accelSqrt()));
 
mySensor.magUpdate();
Serial.println("print mag values");
Serial.println("magX: " + String(mySensor.magX()));
Serial.println("maxY: " + String(mySensor.magY()));
Serial.println("magZ: " + String(mySensor.magZ()));
Serial.println("horizontal direction: " + String(mySensor.magHorizDirection()));
 
Serial.println("at " + String(millis()) + "ms");
delay(500);
}
